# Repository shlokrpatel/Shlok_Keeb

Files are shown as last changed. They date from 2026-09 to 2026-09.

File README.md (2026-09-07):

# Shlok_Keeb
FOR SUBMISSION PURPOSES- here is the link to my project that I completely recorded with lapse- https://lapse.hackclub.com/user/@shlok_r_patel10

a custom keyboard I built myself. This includes the pcb, case, firmware, and eventually, the assembly. I built this to learn more on how to design pcb's and get better at CAD

Built as part of Hackclub's YSWS Keeb

# Features
Custom pcb made in kicad
MX switches
Qmk software
3d printed case
Individually lit rgbs for each key
Rotary Encoder
Oled Screen

# Why I build it
I love building things on my computer and seeing them come to life as I build it. I've been working at getting better at using CAD so whenever I have a chance to improve them with another skill I always take it. 

I was able to learn how to use Kicad, CAD, some firmware use, how to solder, and the engineering behind keyboard

# Design Process
I started in Kicad, I modeled the schematic with all my keys, leds, the microcontroller, oled, and rotary encoder. Then I moved to the actually pcb routing the traces, and placing the keys where i wanted them. After finished that I went to onshape to design the case in 2 peices that will be screwed or glued together. After that I went to the qmk software to write the firmware. 

# Components
Custom PCB
Raspberri pi pico
MX switches
Stabilizers
Usb cable
3D printed case
keycaps
Sk6812 Mini-e LEDs
EC11 rotary encoder
0.91in OLED display

# Challenges
My biggest challenges were:

Learned onshape 
routing my pcb with all the traces
building my case 
writing the firmware

# Images

Matrix schematic


PCB



Case



Bill of Materials(BOM)
| SI No. | Name | Notes | Quantity | Price/Unit (USD) | Total (USD) | Running Total (USD) | Link |
| --- | --- | --- | --- | --- | --- | --- | --- |
| 1 | 0.91" OLED Display | 128x32 I2C OLED, GND-VCC-SCL-SDA | 1 | $1.09 | $1.09 | $1.09 | https://www.aliexpress.us/item/2251832650376908.html |
| 2 | EC11 Rotary Encoder | ALPS EC11E compatible, vertical, H20mm | 1 | $0.46 | $0.46 | $1.55 | https://www.alibaba.com/product-detail/EC11-rotary-15-20mm-Meihua-Bing_1600985459709.html |
| 3 | Key Switches | MX compatible switches, pack of 10 | 7 | $1.00 | $7.00 | $8.55 | https://www.aliexpress.us/item/3256802192387196.html |
| 4 | SK6812MINI-E | Addressable RGB LED, LCSC C5149201 | 61 | $0.0649 | $3.96 | $12.51 | https://www.lcsc.com/product-detail/C5149201.html |
| 5 | 1N4148 Diodes | 1N4148, pack of 100 | 1 | $0.99 | $0.99 | $13.50 | https://www.aliexpress.com/w/wholesale-diode-1n4148.html |
| 6 | Durock V2 Screw-In Stabilizers | 5 stabilizers | 1 | $16.00 | $16.00 | $29.50 | https://upgradekeyboards.com/products/durock-v2-new-screw-in-stabilizers-clear |
| 7 | Custom PCB | JLCPCB manufactured PCB | 1 | $24.00 | $24.00 | $53.50 | https://jlcpcb.com/ |
| 8 | Thock King Shine Through Black PBT Keycap Set | Black pudding PBT, 61-key, RGB shine-through | 1 | $16.95 | $16.95 | $70.45 | https://www.thockking.com/products/shine-through-black-pbt-keycap-set-61-78-87-96-100-104-108 |
| 9 | Raspberry Pi Pico | RP2040 microcontroller | 1 | $4.00 | $4.00 | $74.45 | https://www.raspberrypi.com/products/raspberry-pi-pico/ |

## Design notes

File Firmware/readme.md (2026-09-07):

# shlok_keeb1

shlok_keeb1

*A short description of the keyboard/project*

* Keyboard Maintainer: [Shlok](https://github.com/shlokrpatel)
* Hardware Supported: *The PCBs, controllers supported*
* Hardware Availability: *Links to where you can find this hardware*

Make example for this keyboard (after setting up your build environment):

    make shlok_keeb1:default

Flashing example for this keyboard:

    make shlok_keeb1:default:flash

See the [build environment setup](https://docs.qmk.fm/#/getting_started_build_tools) and the [make instructions](https://docs.qmk.fm/#/getting_started_make_guide) for more information. Brand new to QMK? Start with our [Complete Newbs Guide](https://docs.qmk.fm/#/newbs).

## Bootloader

Enter the bootloader in 3 ways:

* **Bootmagic reset**: Hold down the key at (0,0) in the matrix (usually the top left key or Escape) and plug in the keyboard
* **Physical reset button**: Briefly press the button on the back of the PCB - some may have pads you must short instead
* **Keycode in layout**: Press the key mapped to `QK_BOOT` if it is available

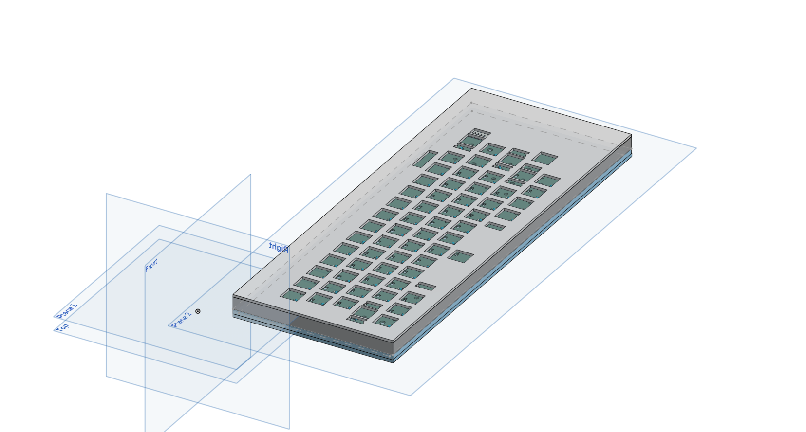
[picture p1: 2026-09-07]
Photos/Screenshot 2026-09-07 120703.png

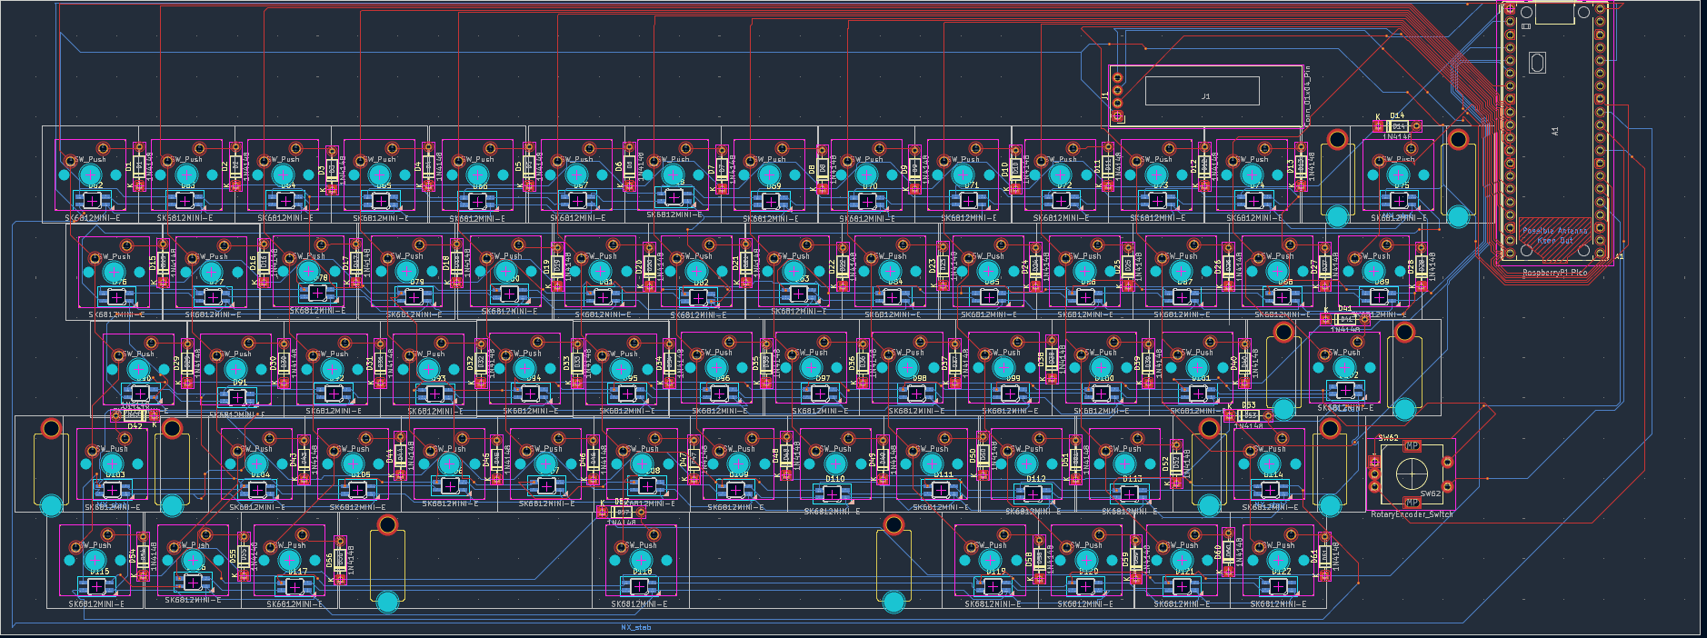
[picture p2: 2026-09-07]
Photos/Screenshot 2026-09-07 000004.png

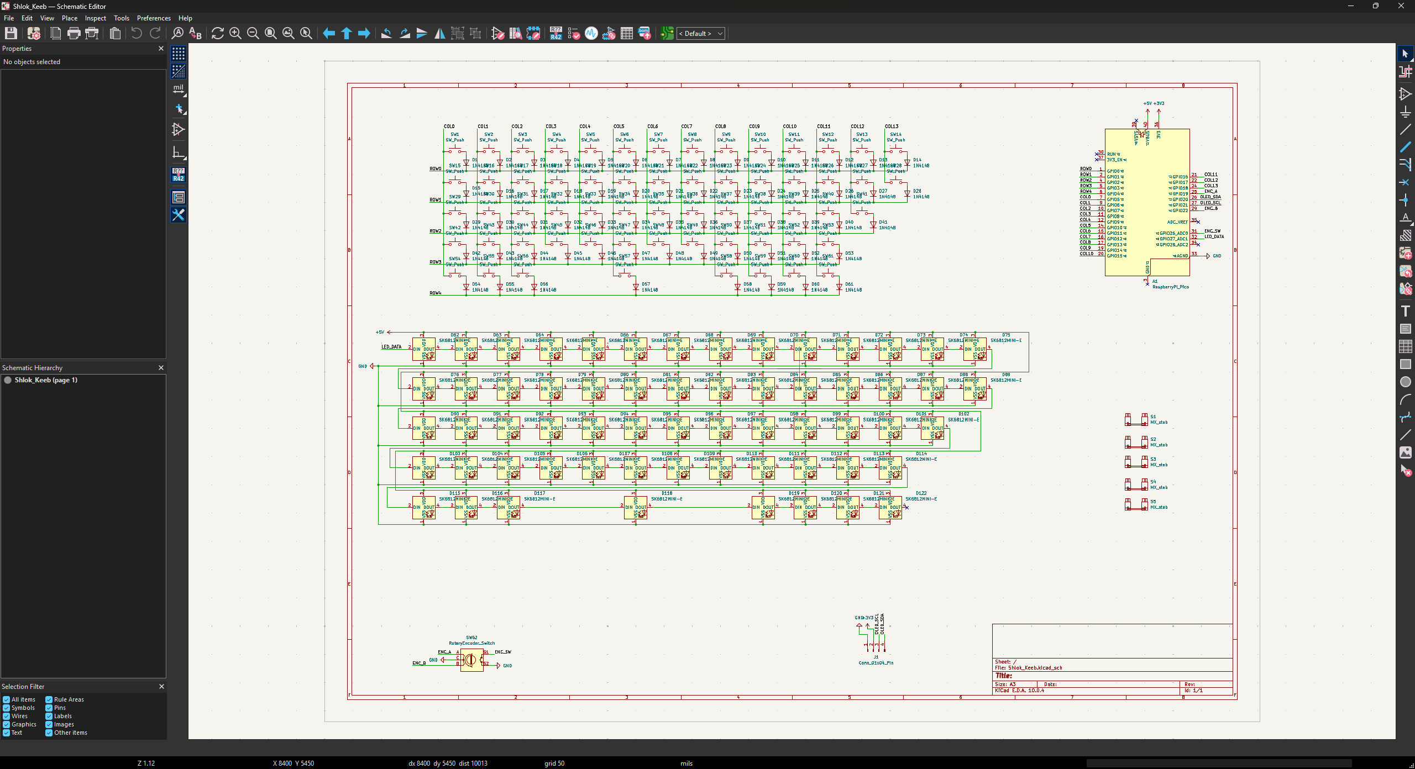
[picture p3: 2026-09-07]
Photos/Screenshot 2026-09-05 150206.png

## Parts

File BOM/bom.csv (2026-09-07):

Item Name | Notes | Quantity | Price Per Unit (USD) | Total Cost (USD) | Link
0.91" OLED Display | 128x32 I2C OLED, GND-VCC-SCL-SDA | 1 | 1.09 | 1.09 | https://www.aliexpress.us/item/2251832650376908.html
EC11 Rotary Encoder | ALPS EC11E compatible, vertical, H20mm | 1 | 0.46 | 0.46 | https://www.alibaba.com/product-detail/EC11-rotary-15-20mm-Meihua-Bing_1600985459709.html
Key Switches | MX compatible switches, pack of 10 | 7 | 1.00 | 7.00 | https://www.aliexpress.us/item/3256802192387196.html
SK6812MINI-E | Addressable RGB LED, LCSC C5149201 | 61 | 0.0649 | 3.96 | https://www.lcsc.com/product-detail/C5149201.html
1N4148 Diodes | 1N4148, pack of 100 | 1 | 0.99 | 0.99 | https://www.aliexpress.com/w/wholesale-diode-1n4148.html
Durock V2 Screw-In Stabilizers | 5 stabilizers | 1 | 16.00 | 16.00 | https://upgradekeyboards.com/products/durock-v2-new-screw-in-stabilizers-clear
Custom PCB | JLCPCB manufactured PCB | 1 | 24.00 | 24.00 | https://jlcpcb.com/
Thock King Shine Through Black PBT Keycap Set | Black pudding PBT, 61-key, RGB shine-through | 1 | 16.95 | 16.95 | https://www.thockking.com/products/shine-through-black-pbt-keycap-set-61-78-87-96-100-104-108
Raspberry Pi Pico | RP2040 microcontroller | 1 | 4.00 | 4.00 | https://www.raspberrypi.com/products/raspberry-pi-pico/
TOTAL |  |  |  | 74.45

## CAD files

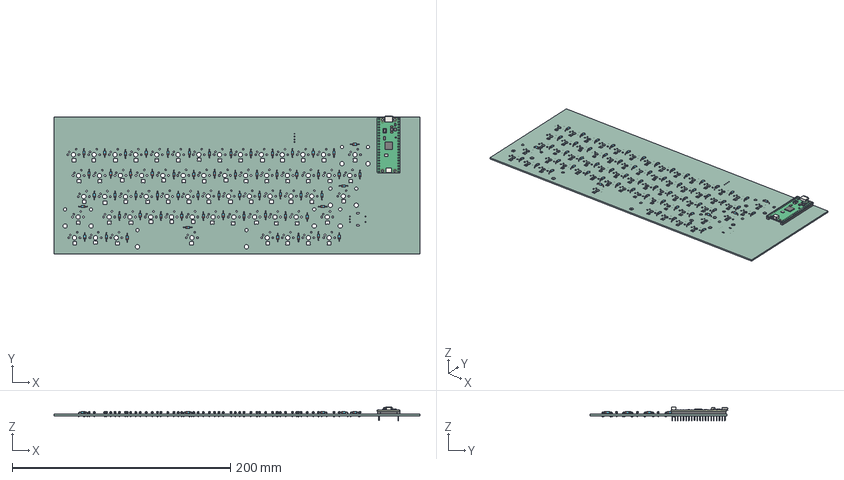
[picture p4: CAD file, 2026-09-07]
CAD/keeb.step
335.7 x 126.3 x 12.8 mm
D_DO-35_SOD27_P7.62mm_Horizontal x 61
RaspberryPi_Pico_H_Module_KiCad
RaspberryPi_Pico_Header_DIP-40_H2.54mm_KiCad
Shlok_Keeb_PCB

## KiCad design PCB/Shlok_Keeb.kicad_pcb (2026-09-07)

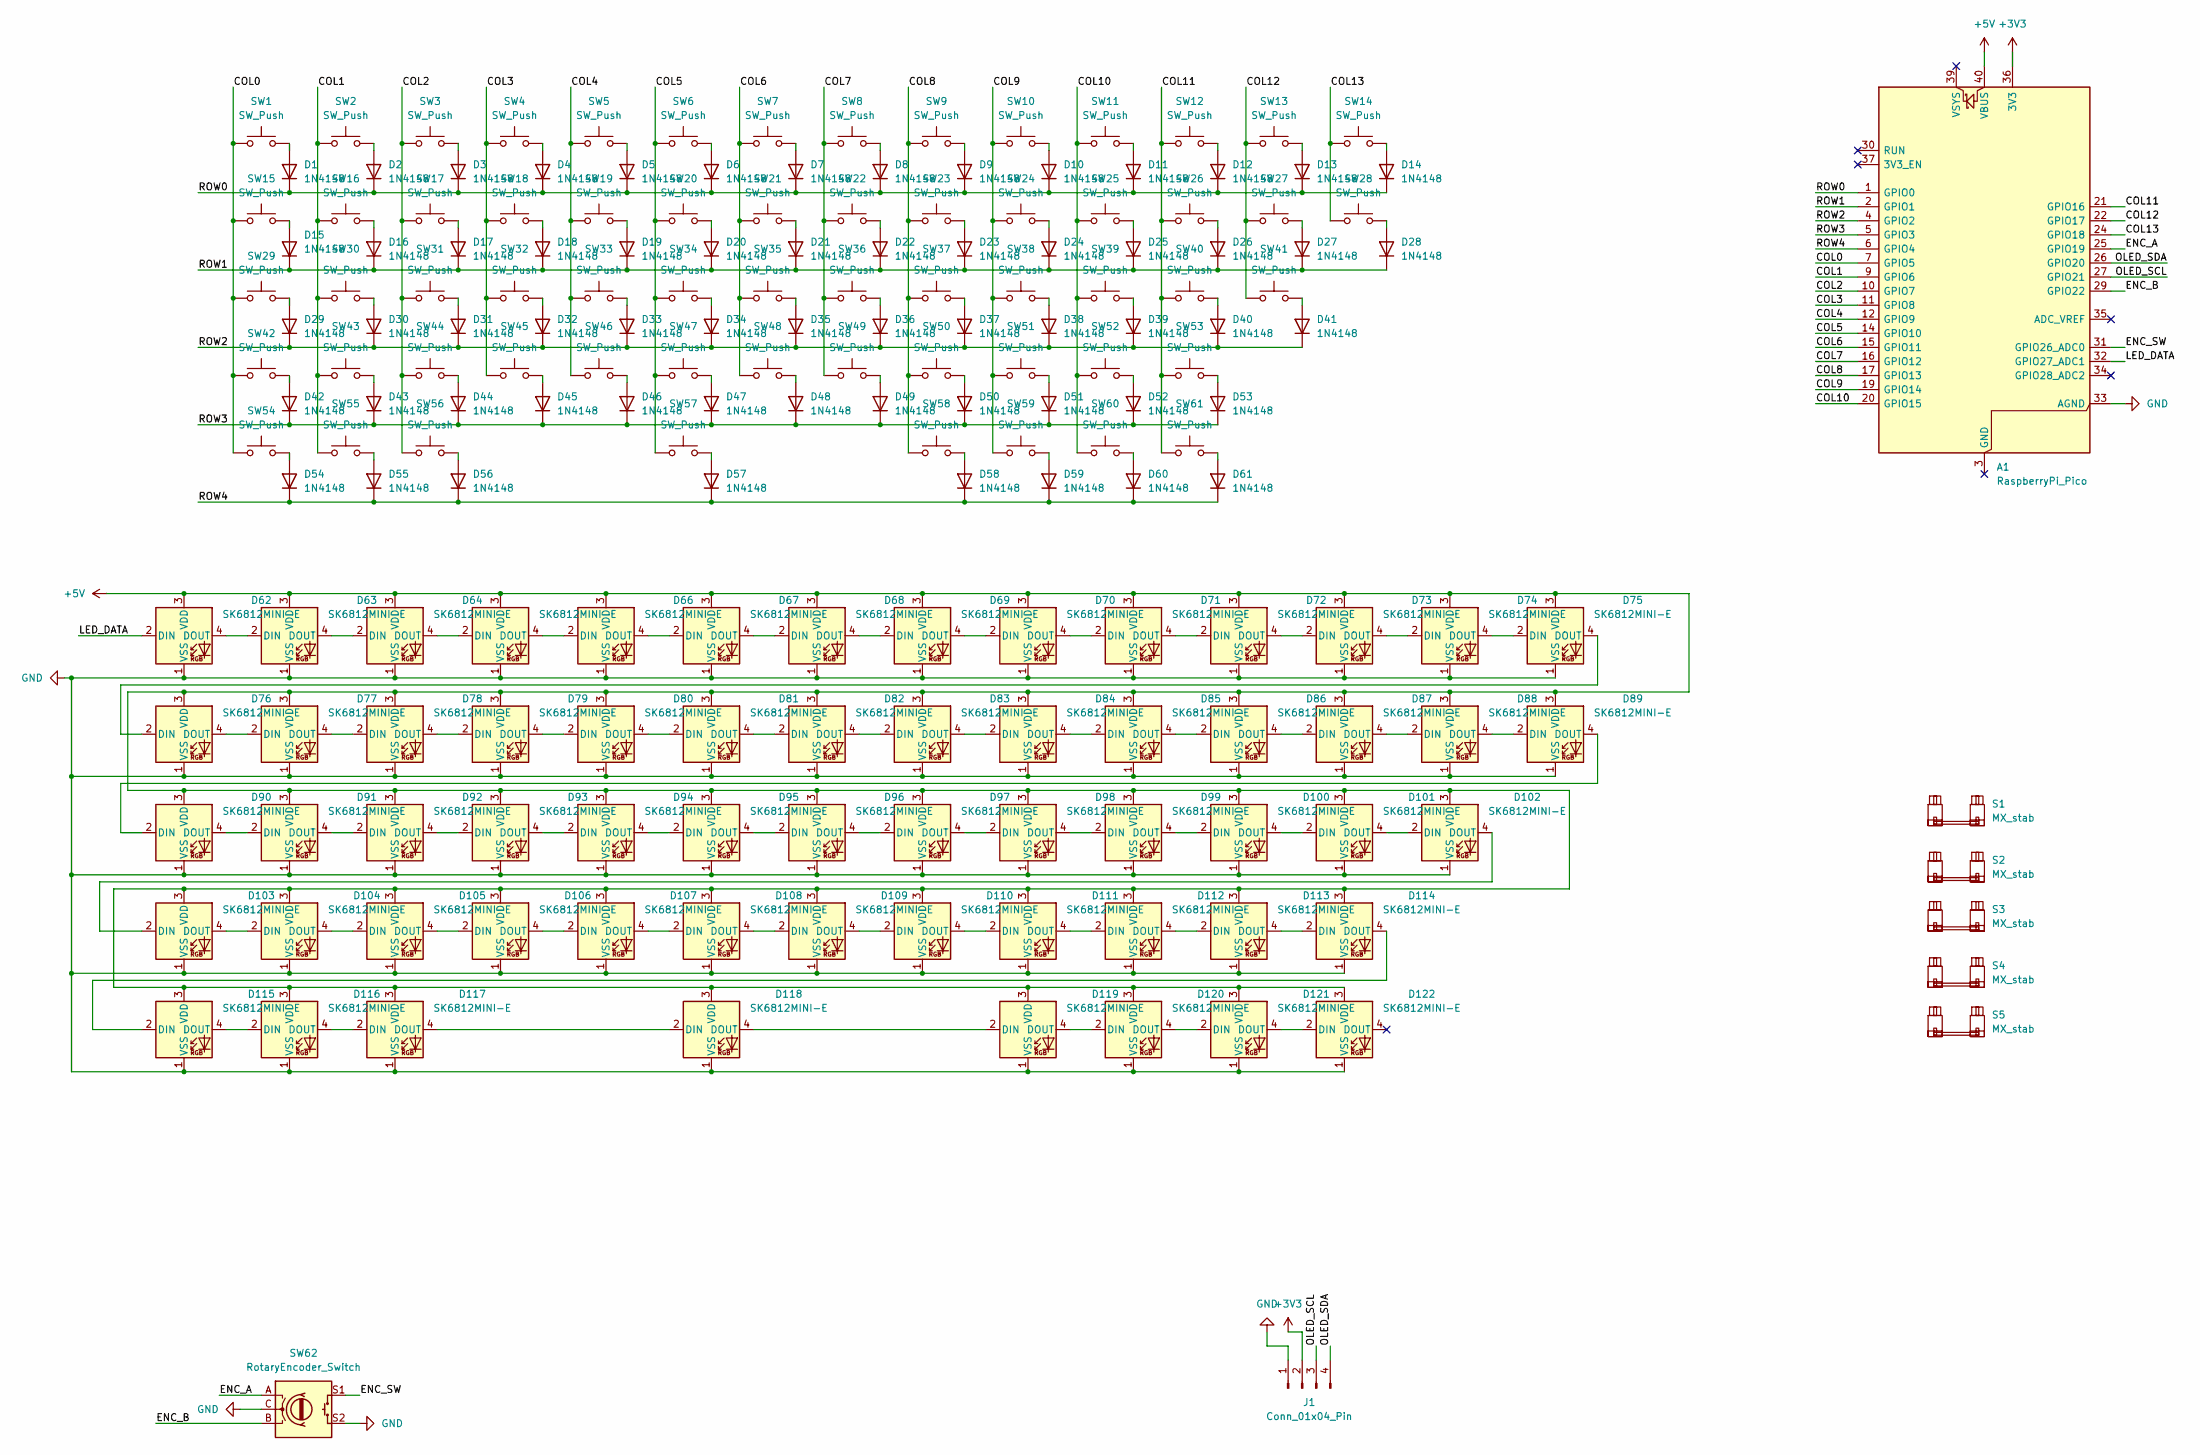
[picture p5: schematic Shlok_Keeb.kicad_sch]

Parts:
A1: RaspberryPi_Pico; RaspberryPi_Pico_Common_THT
D1, D2, D3, D4, D5, D6, D7, D8, D9, D10, D11, D12, D13, D14, D15, D16, D17, D18, D19, D20, D21, D22, D23, D24, D25, D26, D27, D28, D29, D30, D31, D32, D33, D34, D35, D36, D37, D38, D39, D40, D41, D42, D43, D44, D45, D46, D47, D48, D49, D50, D51, D52, D53, D54, D55, D56, D57, D58, D59, D60, D61: 1N4148; D_DO-35_SOD27_P7.62mm_Horizontal
D62, D63, D64, D65, D66, D67, D68, D69, D70, D71, D72, D73, D74, D75, D76, D77, D78, D79, D80, D81, D82, D83, D84, D85, D86, D87, D88, D89, D90, D91, D92, D93, D94, D95, D96, D97, D98, D99, D100, D101, D102, D103, D104, D105, D106, D107, D108, D109, D110, D111, D112, D113, D114, D115, D116, D117, D118, D119, D120, D121, D122: SK6812MINI-E; SK6812MINI-E_fixed
J1: Conn_01x04_Pin; ER_OLEDM0.91_1x-I2C
S1: MX_stab; STAB_MX_P_6.25u
S2, S3, S4, S5: MX_stab; STAB_MX_P_2u
SW1, SW2, SW3, SW4, SW5, SW6, SW7, SW8, SW9, SW10, SW11, SW12, SW13, SW14, SW15, SW16, SW17, SW18, SW19, SW20, SW21, SW22, SW23, SW24, SW25, SW26, SW27, SW28, SW29, SW30, SW31, SW32, SW33, SW34, SW35, SW36, SW37, SW38, SW39, SW40, SW41, SW42, SW43, SW44, SW45, SW46, SW47, SW48, SW49, SW50, SW51, SW52, SW53, SW54, SW55, SW56, SW57, SW58, SW59, SW60, SW61: SW_Push; SW_MX_1u
SW62: RotaryEncoder_Switch; RotaryEncoder_Alps_EC11E-Switch_Vertical_H20mm

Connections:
+3V3: A1.36 (3V3), J1.2
+5V: A1.40 (VBUS), D62.3 (VDD), D63.3 (VDD), D64.3 (VDD), D65.3 (VDD), D66.3 (VDD), D67.3 (VDD), D68.3 (VDD), D69.3 (VDD), D70.3 (VDD), D71.3 (VDD), D72.3 (VDD), D73.3 (VDD), D74.3 (VDD), D75.3 (VDD), D76.3 (VDD), D77.3 (VDD), D78.3 (VDD), D79.3 (VDD), D80.3 (VDD), D81.3 (VDD), D82.3 (VDD), D83.3 (VDD), D84.3 (VDD), D85.3 (VDD), D86.3 (VDD), D87.3 (VDD), D88.3 (VDD), D89.3 (VDD), D90.3 (VDD), D91.3 (VDD), D92.3 (VDD), D93.3 (VDD), D94.3 (VDD), D95.3 (VDD), D96.3 (VDD), D97.3 (VDD), D98.3 (VDD), D99.3 (VDD), D100.3 (VDD), D101.3 (VDD), D102.3 (VDD), D103.3 (VDD), D104.3 (VDD), D105.3 (VDD), D106.3 (VDD), D107.3 (VDD), D108.3 (VDD), D109.3 (VDD), D110.3 (VDD), D111.3 (VDD), D112.3 (VDD), D113.3 (VDD), D114.3 (VDD), D115.3 (VDD), D116.3 (VDD), D117.3 (VDD), D118.3 (VDD), D119.3 (VDD), D120.3 (VDD), D121.3 (VDD), D122.3 (VDD)
/COL0: A1.7 (GPIO5), SW1.1, SW15.1, SW29.1, SW42.1, SW54.1
/COL1: A1.9 (GPIO6), SW2.1, SW16.1, SW30.1, SW43.1, SW55.1
/COL2: A1.10 (GPIO7), SW3.1, SW17.1, SW31.1, SW44.1, SW56.1
/COL3: A1.11 (GPIO8), SW4.1, SW18.1, SW32.1, SW45.1
/COL4: A1.12 (GPIO9), SW5.1, SW19.1, SW33.1, SW46.1
/COL5: A1.14 (GPIO10), SW6.1, SW20.1, SW34.1, SW47.1, SW57.1
/COL6: A1.15 (GPIO11), SW7.1, SW21.1, SW35.1, SW48.1
/COL7: A1.16 (GPIO12), SW8.1, SW22.1, SW36.1, SW49.1
/COL8: A1.17 (GPIO13), SW9.1, SW23.1, SW37.1, SW50.1, SW58.1
/COL9: A1.19 (GPIO14), SW10.1, SW24.1, SW38.1, SW51.1, SW59.1
/COL10: A1.20 (GPIO15), SW11.1, SW25.1, SW39.1, SW52.1, SW60.1
/COL11: A1.21 (GPIO16), SW12.1, SW26.1, SW40.1, SW53.1, SW61.1
/COL12: A1.22 (GPIO17), SW13.1, SW27.1, SW41.1
/COL13: A1.24 (GPIO18), SW14.1, SW28.1
/ENC_A: A1.25 (GPIO19), SW62.A
/ENC_B: A1.29 (GPIO22), SW62.B
/ENC_SW: A1.31 (GPIO26_ADC0), SW62.S1
/LED_DATA: A1.32 (GPIO27_ADC1), D62.2 (DIN)
/OLED_SCL: A1.27 (GPIO21), J1.3
/OLED_SDA: A1.26 (GPIO20), J1.4
/ROW0: A1.1 (GPIO0), D1.1 (K), D2.1 (K), D3.1 (K), D4.1 (K), D5.1 (K), D6.1 (K), D7.1 (K), D8.1 (K), D9.1 (K), D10.1 (K), D11.1 (K), D12.1 (K), D13.1 (K), D14.1 (K)
/ROW1: A1.2 (GPIO1), D15.1 (K), D16.1 (K), D17.1 (K), D18.1 (K), D19.1 (K), D20.1 (K), D21.1 (K), D22.1 (K), D23.1 (K), D24.1 (K), D25.1 (K), D26.1 (K), D27.1 (K), D28.1 (K)
/ROW2: A1.4 (GPIO2), D29.1 (K), D30.1 (K), D31.1 (K), D32.1 (K), D33.1 (K), D34.1 (K), D35.1 (K), D36.1 (K), D37.1 (K), D38.1 (K), D39.1 (K), D40.1 (K), D41.1 (K)
/ROW3: A1.5 (GPIO3), D42.1 (K), D43.1 (K), D44.1 (K), D45.1 (K), D46.1 (K), D47.1 (K), D48.1 (K), D49.1 (K), D50.1 (K), D51.1 (K), D52.1 (K), D53.1 (K)
/ROW4: A1.6 (GPIO4), D54.1 (K), D55.1 (K), D56.1 (K), D57.1 (K), D58.1 (K), D59.1 (K), D60.1 (K), D61.1 (K)
GND: A1.33 (AGND), D62.1 (VSS), D63.1 (VSS), D64.1 (VSS), D65.1 (VSS), D66.1 (VSS), D67.1 (VSS), D68.1 (VSS), D69.1 (VSS), D70.1 (VSS), D71.1 (VSS), D72.1 (VSS), D73.1 (VSS), D74.1 (VSS), D75.1 (VSS), D76.1 (VSS), D77.1 (VSS), D78.1 (VSS), D79.1 (VSS), D80.1 (VSS), D81.1 (VSS), D82.1 (VSS), D83.1 (VSS), D84.1 (VSS), D85.1 (VSS), D86.1 (VSS), D87.1 (VSS), D88.1 (VSS), D89.1 (VSS), D90.1 (VSS), D91.1 (VSS), D92.1 (VSS), D93.1 (VSS), D94.1 (VSS), D95.1 (VSS), D96.1 (VSS), D97.1 (VSS), D98.1 (VSS), D99.1 (VSS), D100.1 (VSS), D101.1 (VSS), D102.1 (VSS), D103.1 (VSS), D104.1 (VSS), D105.1 (VSS), D106.1 (VSS), D107.1 (VSS), D108.1 (VSS), D109.1 (VSS), D110.1 (VSS), D111.1 (VSS), D112.1 (VSS), D113.1 (VSS), D114.1 (VSS), D115.1 (VSS), D116.1 (VSS), D117.1 (VSS), D118.1 (VSS), D119.1 (VSS), D120.1 (VSS), D121.1 (VSS), D122.1 (VSS), J1.1, SW62.C, SW62.S2
unnamed: D1.2 (A), SW1.2
unnamed: D2.2 (A), SW2.2
unnamed: D3.2 (A), SW3.2
unnamed: D4.2 (A), SW4.2
unnamed: D5.2 (A), SW5.2
unnamed: D6.2 (A), SW6.2
unnamed: D7.2 (A), SW7.2
unnamed: D8.2 (A), SW8.2
unnamed: D9.2 (A), SW9.2
unnamed: D10.2 (A), SW10.2
unnamed: D11.2 (A), SW11.2
unnamed: D12.2 (A), SW12.2
unnamed: D13.2 (A), SW13.2
unnamed: D14.2 (A), SW14.2
unnamed: D15.2 (A), SW15.2
unnamed: D16.2 (A), SW16.2
unnamed: D17.2 (A), SW17.2
unnamed: D18.2 (A), SW18.2
unnamed: D19.2 (A), SW19.2
unnamed: D20.2 (A), SW20.2
unnamed: D21.2 (A), SW21.2
unnamed: D22.2 (A), SW22.2
unnamed: D23.2 (A), SW23.2
unnamed: D24.2 (A), SW24.2
unnamed: D25.2 (A), SW25.2
unnamed: D26.2 (A), SW26.2
unnamed: D27.2 (A), SW27.2
unnamed: D28.2 (A), SW28.2
unnamed: D29.2 (A), SW29.2
unnamed: D30.2 (A), SW30.2
unnamed: D31.2 (A), SW31.2
unnamed: D32.2 (A), SW32.2
unnamed: D33.2 (A), SW33.2
unnamed: D34.2 (A), SW34.2
unnamed: D35.2 (A), SW35.2
unnamed: D36.2 (A), SW36.2
unnamed: D37.2 (A), SW37.2
unnamed: D38.2 (A), SW38.2
unnamed: D39.2 (A), SW39.2
unnamed: D40.2 (A), SW40.2
unnamed: D41.2 (A), SW41.2
unnamed: D42.2 (A), SW42.2
unnamed: D43.2 (A), SW43.2
unnamed: D44.2 (A), SW44.2
unnamed: D45.2 (A), SW45.2
unnamed: D46.2 (A), SW46.2
unnamed: D47.2 (A), SW47.2
unnamed: D48.2 (A), SW48.2
unnamed: D49.2 (A), SW49.2
unnamed: D50.2 (A), SW50.2
unnamed: D51.2 (A), SW51.2
unnamed: D52.2 (A), SW52.2
unnamed: D53.2 (A), SW53.2
unnamed: D54.2 (A), SW54.2
unnamed: D55.2 (A), SW55.2
unnamed: D56.2 (A), SW56.2
unnamed: D57.2 (A), SW57.2
unnamed: D58.2 (A), SW58.2
unnamed: D59.2 (A), SW59.2
unnamed: D60.2 (A), SW60.2
unnamed: D61.2 (A), SW61.2
unnamed: D62.4 (DOUT), D63.2 (DIN)
unnamed: D63.4 (DOUT), D64.2 (DIN)
unnamed: D64.4 (DOUT), D65.2 (DIN)
unnamed: D65.4 (DOUT), D66.2 (DIN)
unnamed: D66.4 (DOUT), D67.2 (DIN)
unnamed: D67.4 (DOUT), D68.2 (DIN)
unnamed: D68.4 (DOUT), D69.2 (DIN)
unnamed: D69.4 (DOUT), D70.2 (DIN)
unnamed: D70.4 (DOUT), D71.2 (DIN)
unnamed: D71.4 (DOUT), D72.2 (DIN)
unnamed: D72.4 (DOUT), D73.2 (DIN)
unnamed: D73.4 (DOUT), D74.2 (DIN)
unnamed: D74.4 (DOUT), D75.2 (DIN)
unnamed: D75.4 (DOUT), D76.2 (DIN)
unnamed: D76.4 (DOUT), D77.2 (DIN)
unnamed: D77.4 (DOUT), D78.2 (DIN)
unnamed: D78.4 (DOUT), D79.2 (DIN)
unnamed: D79.4 (DOUT), D80.2 (DIN)
unnamed: D80.4 (DOUT), D81.2 (DIN)
unnamed: D81.4 (DOUT), D82.2 (DIN)
unnamed: D82.4 (DOUT), D83.2 (DIN)
unnamed: D83.4 (DOUT), D84.2 (DIN)
unnamed: D84.4 (DOUT), D85.2 (DIN)
unnamed: D85.4 (DOUT), D86.2 (DIN)
unnamed: D86.4 (DOUT), D87.2 (DIN)
unnamed: D87.4 (DOUT), D88.2 (DIN)
unnamed: D88.4 (DOUT), D89.2 (DIN)
unnamed: D89.4 (DOUT), D90.2 (DIN)
unnamed: D90.4 (DOUT), D91.2 (DIN)
unnamed: D91.4 (DOUT), D92.2 (DIN)
unnamed: D92.4 (DOUT), D93.2 (DIN)
unnamed: D93.4 (DOUT), D94.2 (DIN)
unnamed: D94.4 (DOUT), D95.2 (DIN)
unnamed: D95.4 (DOUT), D96.2 (DIN)
unnamed: D96.4 (DOUT), D97.2 (DIN)
unnamed: D97.4 (DOUT), D98.2 (DIN)
unnamed: D98.4 (DOUT), D99.2 (DIN)
unnamed: D99.4 (DOUT), D100.2 (DIN)
unnamed: D100.4 (DOUT), D101.2 (DIN)
unnamed: D101.4 (DOUT), D102.2 (DIN)
unnamed: D102.4 (DOUT), D103.2 (DIN)
unnamed: D103.4 (DOUT), D104.2 (DIN)
unnamed: D104.4 (DOUT), D105.2 (DIN)
unnamed: D105.4 (DOUT), D106.2 (DIN)
unnamed: D106.4 (DOUT), D107.2 (DIN)
unnamed: D107.4 (DOUT), D108.2 (DIN)
unnamed: D108.4 (DOUT), D109.2 (DIN)
unnamed: D109.4 (DOUT), D110.2 (DIN)
unnamed: D110.4 (DOUT), D111.2 (DIN)
unnamed: D111.4 (DOUT), D112.2 (DIN)
unnamed: D112.4 (DOUT), D113.2 (DIN)
unnamed: D113.4 (DOUT), D114.2 (DIN)
unnamed: D114.4 (DOUT), D115.2 (DIN)
unnamed: D115.4 (DOUT), D116.2 (DIN)
unnamed: D116.4 (DOUT), D117.2 (DIN)
unnamed: D117.4 (DOUT), D118.2 (DIN)
unnamed: D118.4 (DOUT), D119.2 (DIN)
unnamed: D119.4 (DOUT), D120.2 (DIN)
unnamed: D120.4 (DOUT), D121.2 (DIN)
unnamed: D121.4 (DOUT), D122.2 (DIN)

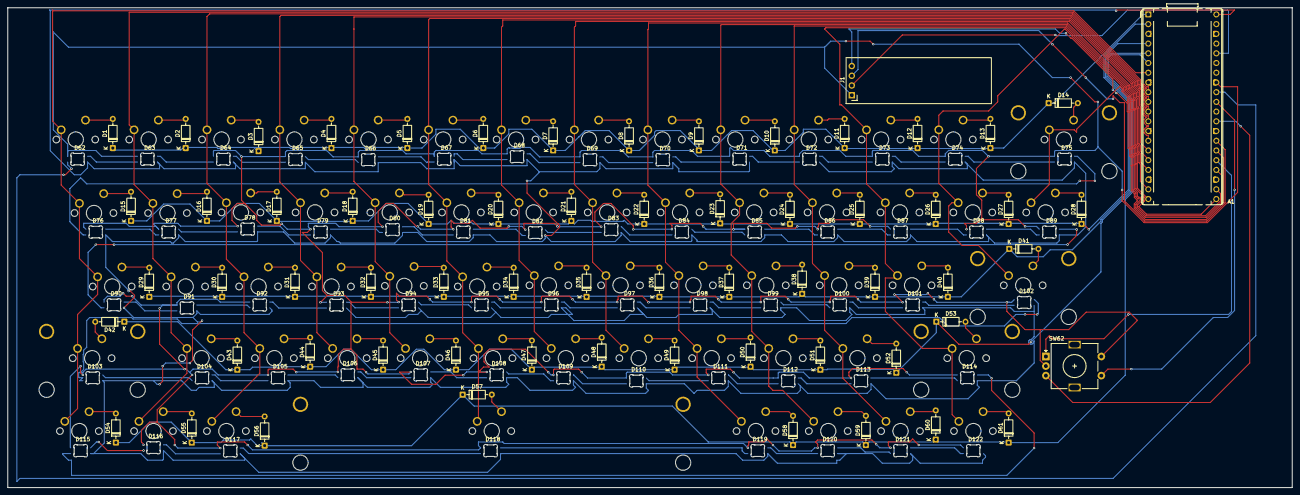
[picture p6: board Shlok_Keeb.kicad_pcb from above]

Board: 2 copper layers, 335.7 x 125.4 mm, 191 parts (0 on the bottom side), 149 nets.

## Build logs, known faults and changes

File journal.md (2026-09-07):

I moved journal entries to https://lapse.hackclub.com/user/@shlok_r_patel10

## Entry 1: Schematic & ERC Fixes
* **Date:** July 11, 2026
* **Time Spent:** 5.5 hours

### What I Did:
Finished the main schematic layout for the custom keyboard. Did lots of research on how I wanted my keyboard to look. Also finished arranging the PCB and started on wiring everything up

### Obstacles:
My keys were moving is a very weird grid so it took about 10 minutes to get that fixed. The ERC threw lots of errors at me but i fixed them pretty easily and got back to designing. 
### Progress Photos:
